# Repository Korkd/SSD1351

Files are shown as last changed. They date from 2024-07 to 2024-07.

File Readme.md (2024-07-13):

Workshopping a breakout board for a SSD1351 128x128 OLED to mount to the left half of a BastardKB Dilemma.

## Goals

* Add slit to remove need to rotate display 180 degrees
* Take advantage of top mounting holes
* Match pinout of Dilemma

Shoutout to Jon Thomasson and [his work](https://github.com/jonthomasson/1.5OLEDBreakout) as it was a great resource.

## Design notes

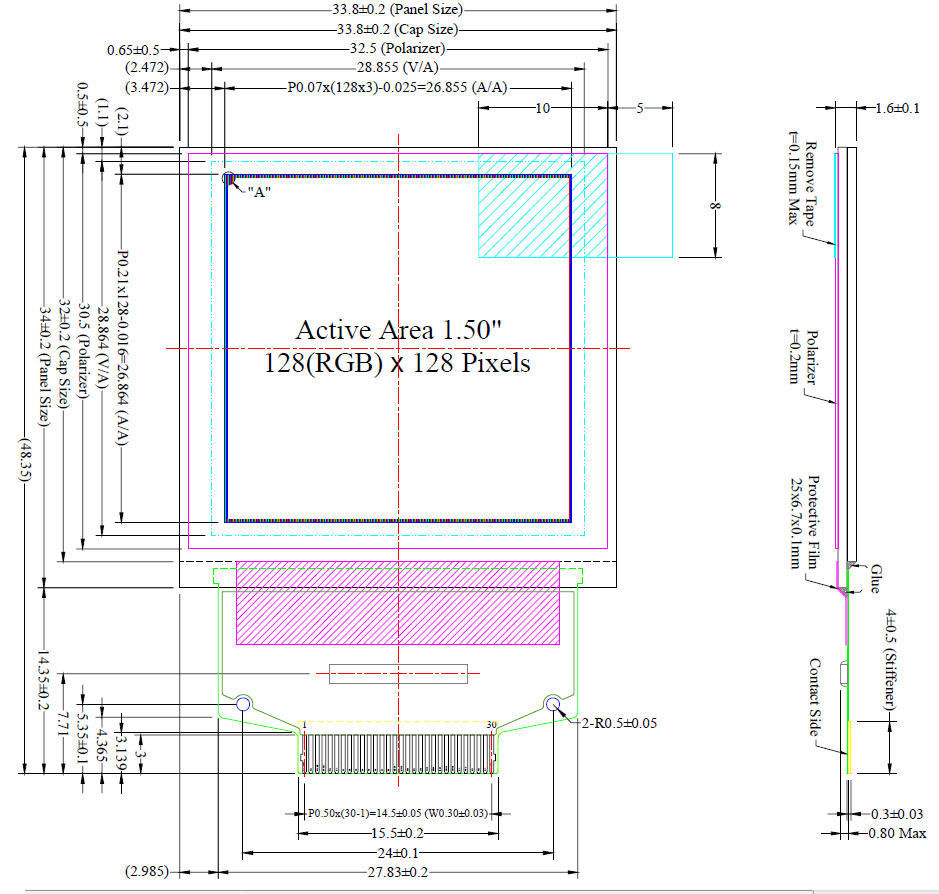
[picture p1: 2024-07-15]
er-oled015-1c_outline.jpg

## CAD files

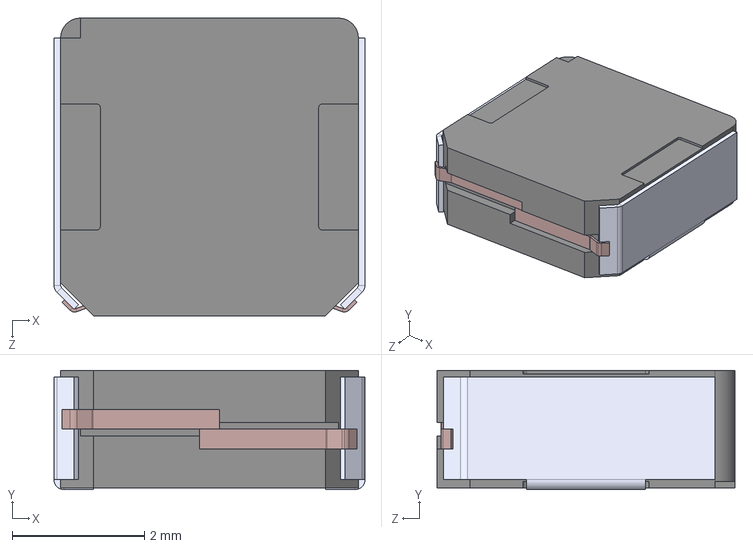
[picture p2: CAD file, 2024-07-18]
PCB/1235AS-H-100M_P3.step
4.70 x 1.80 x 4.50 mm

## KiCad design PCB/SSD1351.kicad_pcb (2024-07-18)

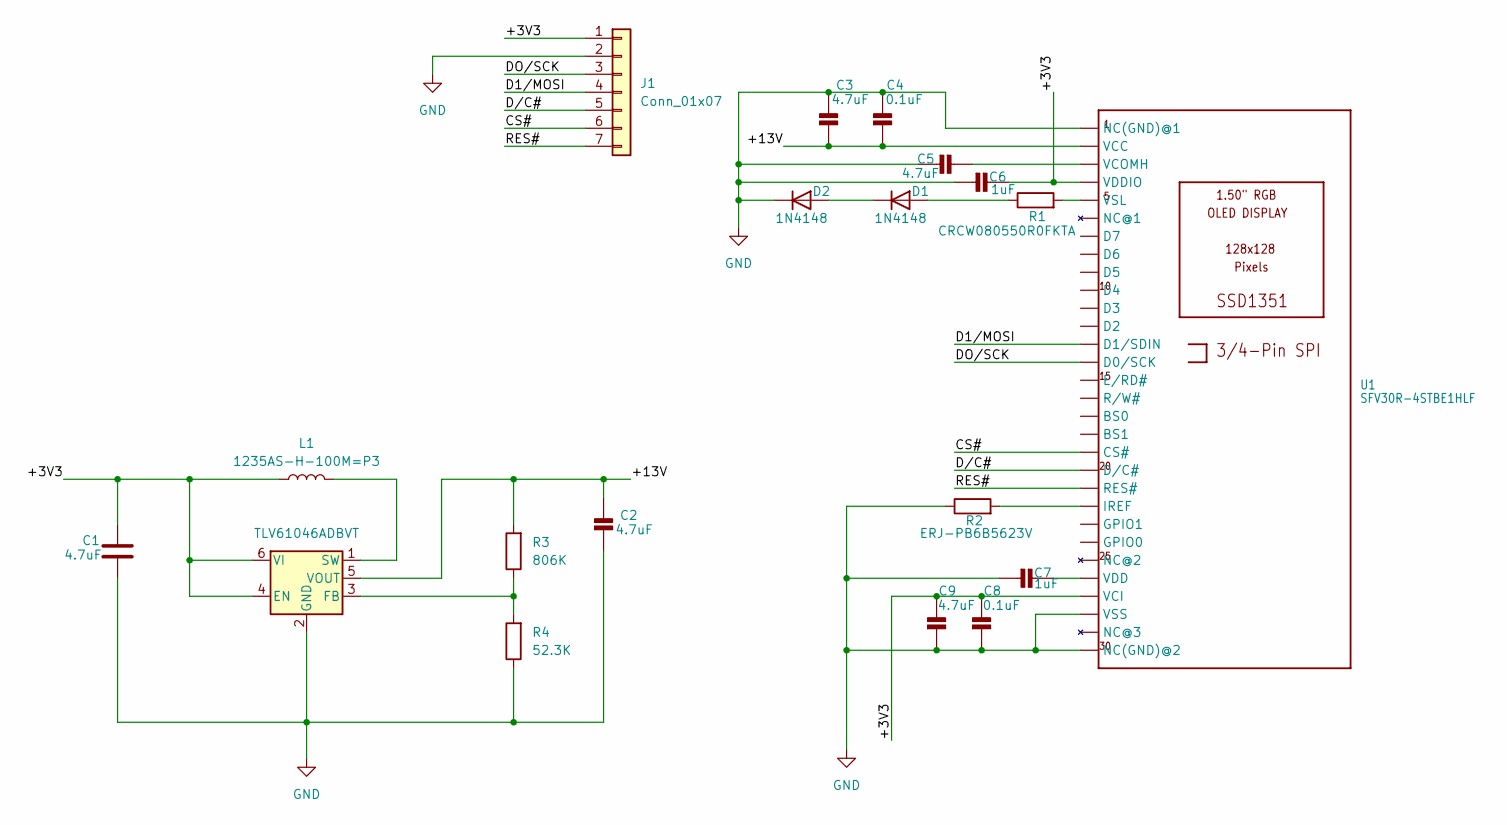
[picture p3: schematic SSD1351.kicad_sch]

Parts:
C1, C9: 4.7uF; C_0805_2012Metric
C2, C3, C5: 4.7uF; C_1206_3216Metric
C4, C8: 0.1uF; C_0603_1608Metric
C6, C7: 1uF; C_0805_2012Metric
D1, D2: 1N4148; D_SOD-323
J1: Conn_01x07; PinHeader_1x07_P2.54mm_Vertical
L1: 1235AS-H-100M=P3; IND_1235AS-H-100M=P3
R1: CRCW080550R0FKTA; R_0805_2012Metric
R2: ERJ-PB6B5623V; R_0805_2012Metric
R3: 806K; R_0805_2012Metric
R4: 52.3K; R_0805_2012Metric
U1: SFV30R-4STBE1HLF; CONNECTORS_FPC_SFV30R_4STBE1HLF
U2: TLV61046ADBVT; SOT-23-6

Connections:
/+3V3: C1.1, C6.1, C8.1, C9.1, J1.1, L1.1, U1.4 (VDDIO), U1.27 (VCI), U2.4 (EN), U2.6 (VI)
/+13V: C2.1, C3.2, C4.2, R3.2, U1.2 (VCC), U2.5 (VOUT)
/CS#: J1.6, U1.19 (CS#)
/D1/MOSI: J1.4, U1.13 (D1/SDIN)
/DO/SCK: J1.3, U1.14 (D0/SCK)
/D/C#: J1.5, U1.20 (D/C#)
/RES#: J1.7, U1.21 (RES#)
GND: C1.2, C2.2, C3.1, C4.1, C5.2, C6.2, C7.2, C8.2, C9.2, D2.1 (K), J1.2, R2.1, R4.1, U1.1 (NC(GND)@1), U1.28 (VSS), U1.30 (NC(GND)@2), U2.2 (GND)
unnamed: C5.1, U1.3 (VCOMH)
unnamed: C7.1, U1.26 (VDD)
unnamed: D1.2 (A), R1.1
unnamed: D1.1 (K), D2.2 (A)
unnamed: R2.2, U1.22 (IREF)
unnamed: R1.2, U1.5 (VSL)
unnamed: R3.1, R4.2, U2.3 (FB)
unnamed: L1.2, U2.1 (SW)

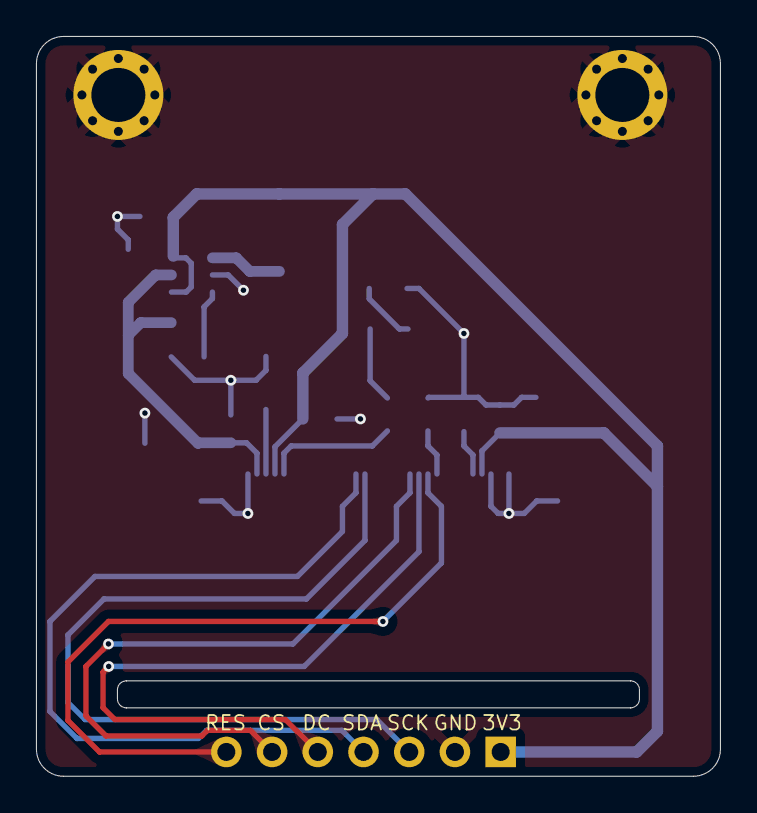
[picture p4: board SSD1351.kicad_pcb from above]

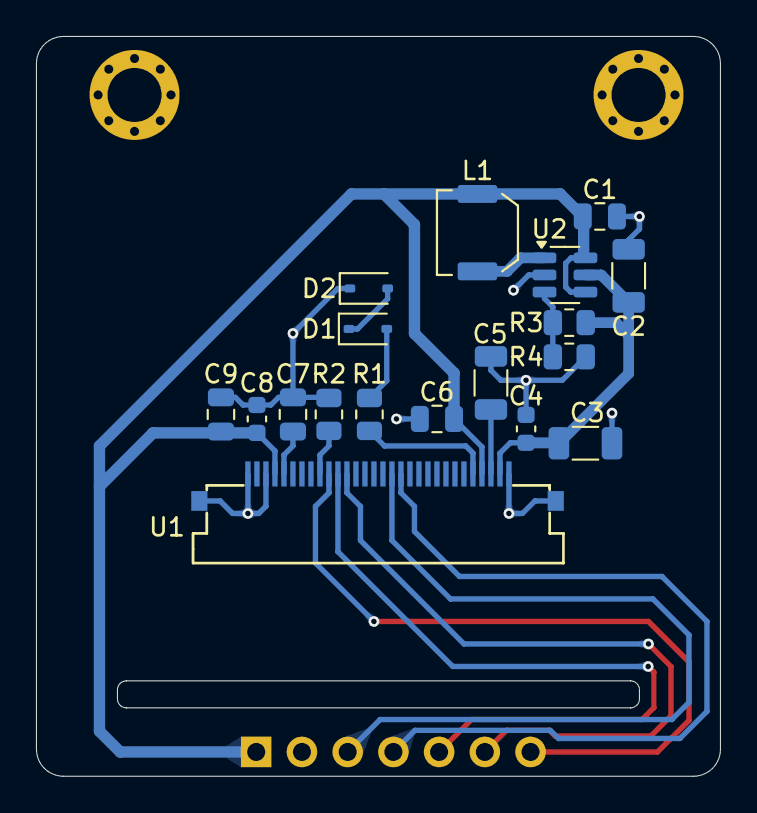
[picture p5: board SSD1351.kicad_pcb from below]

Board: 2 copper layers, 38.0 x 41.1 mm, 19 parts (18 on the bottom side), 16 nets.

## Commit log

2024-07-13 Adding Initial PCB
    Added KiCAD project
    [SSD1351.kicad_pcb, SSD1351.kicad_sch]
2024-07-13 More readme changes
    Adding in goals for the board
2024-07-14 Added SKUs for components
    [SSD1351.kicad_sch]
2024-07-14 Adding a few more SKUs
    [SSD1351.kicad_sch]
2024-07-15 Updated PCB
    Consulted datasheets and adjusted cap ratings.
    Reworked power distribution and location.
    Started tracking down specific components and updating the BOM.
    [SSD1351.kicad_pcb, SSD1351.kicad_sch]
2024-07-16 Adding datasheets and more pcb design changes
    * Added datasheets for ICs
    * Removed unused footprints
    * Updated PCB to use correct sized caps
    [SSD1351.kicad_pcb, SSD1351.kicad_sch]
2024-07-17 Changing 13v boost converter
    Replace the FAN5331 with MIC2288 as a result of some sourcing issues. Redesigned and updated all the relevant components.
    Added in some new footprints to make hand soldering easier for inductor and boost converter.
    [LQH3NPH100MMEL.step, MIC2288YD5-TR.step, SSD1351.kicad_pcb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]
2024-07-18 More power system changes
    Swapping out MLC2288 for TLV61046A and removing redundant diode.
    Also swapped out inductor for a more efficient one.
    [1235AS-H-100M_P3.step, LQH3NPH100MMEL.step, MIC2288YD5-TR.step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]
